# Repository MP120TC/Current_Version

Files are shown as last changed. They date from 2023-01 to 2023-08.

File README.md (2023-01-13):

# MP120TC (Version1, December 2022)
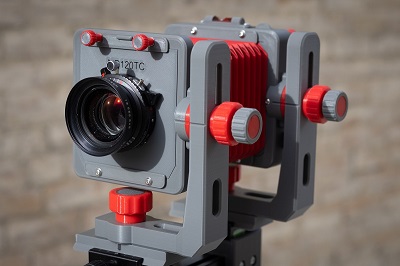
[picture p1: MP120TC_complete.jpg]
MP120TC complete camera


The MP120TC is a 120 film technical camera designed by Kent Williams in 2022.  It has full tilt/shift/swing/rise/fall movements on both the front and rear standards to enable full control of focus plane and geometry just like a large format view camera.  It uses Graflok 23 compatible roll film backs for convenience, and the parts that move most utilize off-the-shelf metal parts for durability, smoothness, and precision.  You can even build your own bellows for it if you're up to the task.  The camera will work with any large format lens in shutter as long as there's enough image circle and you have the proper rail/bellows length combination.  Most of the camera is 3D printed, so when parts wear out, you just print another!

## License
The MP120TC is provided to the community using a [Creative Commons Attribution-NonCommercial 4.0 license](https://creativecommons.org/licenses/by-nc/4.0/)
This means you can Share or Adapt/Remix it, as long as you provide attribution and don't sell the design. See [this page](https://creativecommons.org/licenses/by-nc-sa/4.0/legalcode) for more details.

 

# Website
The MP120TC also has its own website, which can be found here:  [MP120TC Website](https://williamskg6.wixsite.com/mp120tc)
## Why I Designed The MP120TC
In 2021 I got my first 3D printer.  I'd been designing things and having them printed at outlets like Shapeways and Xometry for several years. With this new 3D printer in my possession I decided to print and build an open source 120 film technical camera I had found online.  It looked nice in pictures and all the files were available, so I was pretty sure it'd work ... or so I thought.

Once I started printing parts, I had a realization that the camera had several pretty important faults.  The idea was cool, and it would look nice on the shelf, but it wouldn't really be usable. I first attempted to modify the existing design and immediately ran into more problems, since many design decisions were built into the models that conflicted with the idea of making a usable camera.  I came to the realization that it'd probably be better if I started from scratch and designed my own.

## How It Got Its Name
Early on in my designing process I had discovered a project called the MPCNC, which stands for "Mostly (3D) Printed CNC", which is a CNC router you can build using a combination of 3D printed parts and off-the-shelf hardware.  The idea is to construct the router using mostly 3D printed parts, and augment those parts with hardware that is better suited in only those places where the hardware is better for the task.  I think this is a pretty clever idea, and I adopted it for my 3D printed technical camera.  It is mostly 3D printed, augmented with parts where 3D printing would be less effective.  It's a 120 technical camera, so I named it the Mostly Printed 120 Technical Camera, or MP120TC for short.

## 120 Film Instead of 4x5
There are several reasons I chose 120 film, specifically 6x7cm, over 4x5 inch film:
- There are numerous 4x5 3D printable camera designs already available
- 4x5 inch film is considerably more expensive per shot
- 4x5 inch film is considerably less convenient and much more cumbersome to carry
- 4x5 inch film is much more expensive to develop if you send it to a lab
- 4x5 inch film is a lot more difficult to scan
- 6x7cm image quality is very high and can almost approach the quality of 4x5 inch film
- 120 film is much easier to get and is much less expensive
- If you want to use a lab to process your film, 120 film is much less expensive
- Scanning 120 film is a lot easier and less expensive
- 120 film backs are readily available, made by Mamiya, Graflex, or Horseman

## 6x7 By Default, 6x9 Optional
By default, the MP120TC is a 6x7cm camera that employs the Graflok 23 roll film mount (sometimes called Graflok Mini).  Because Graflok 23 was built to handle it, the MP120TC can also support 6x9 if desired.  I've been asked why I chose 6x7 as the default when I could have gone with 6x9 instead.  Here are the reasons I've chosen 6x7cm by default. 

6x7 film backs are much more plentiful.  The most common 6x9 film backs are from Graflex and Horseman, while with 6x7 you can use Mamiya RB-67 backs, Graflex, and Horseman.  While the Horseman backs are really nice, they're not very easy to get.  Graflex backs are pretty common, but are not as well made as Mamiya and Horseman, nor do they hold film as flat as Mamiya and Horseman backs.

For the 6x7 size, there are more options available for the ground glass, especially from Rick Oleson Bright Screens.  In 6x7 size, you can get screens with many different focusing aids (splits, microprisms, etc.) and lines for other formats.  With 6x9 you can only get plain focusing screens, cut down from 4x5 inch screens.

As you can see, there aren't many reasons, but the film back availability is a pretty important one.  Having said that, those who wish to go for 6x9 can totally do so - the files are included.

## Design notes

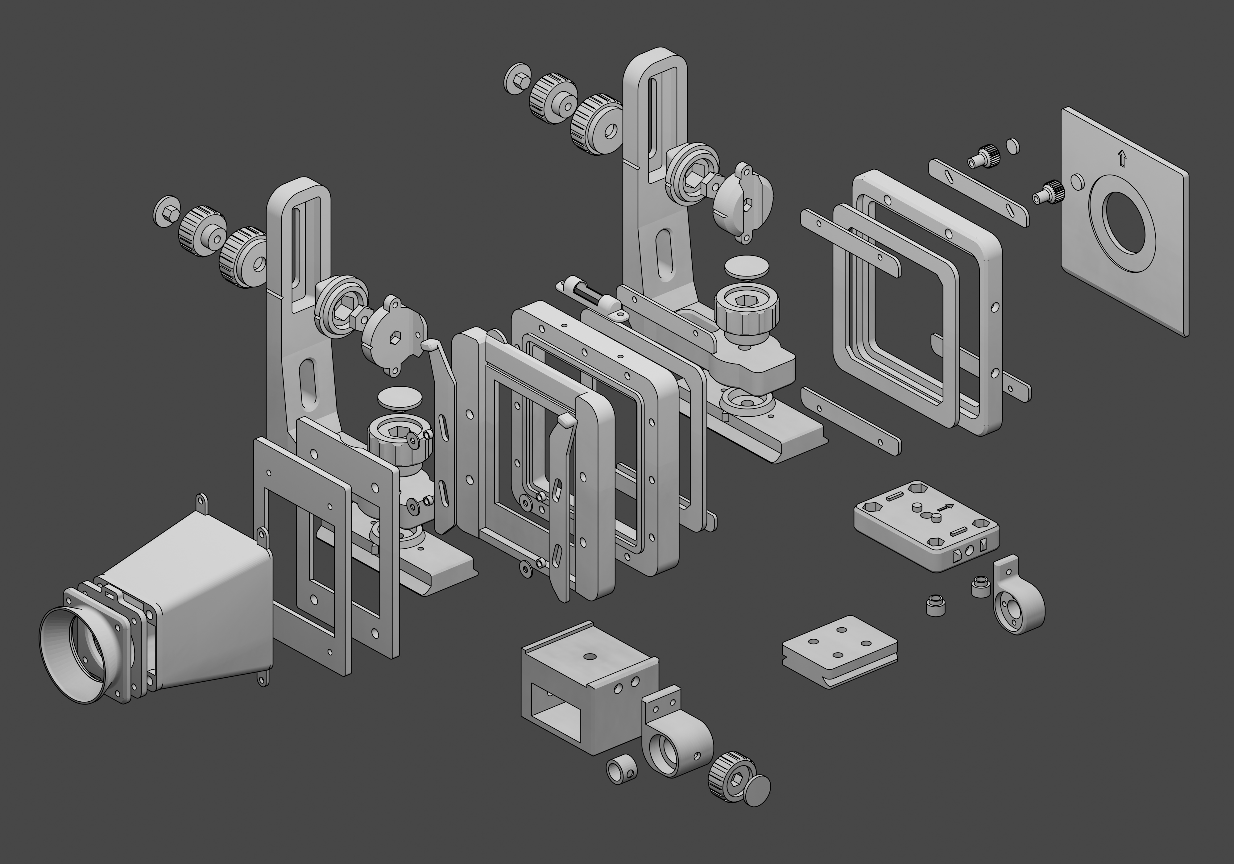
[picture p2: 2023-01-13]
Full_Camera_Exploded_View.jpg

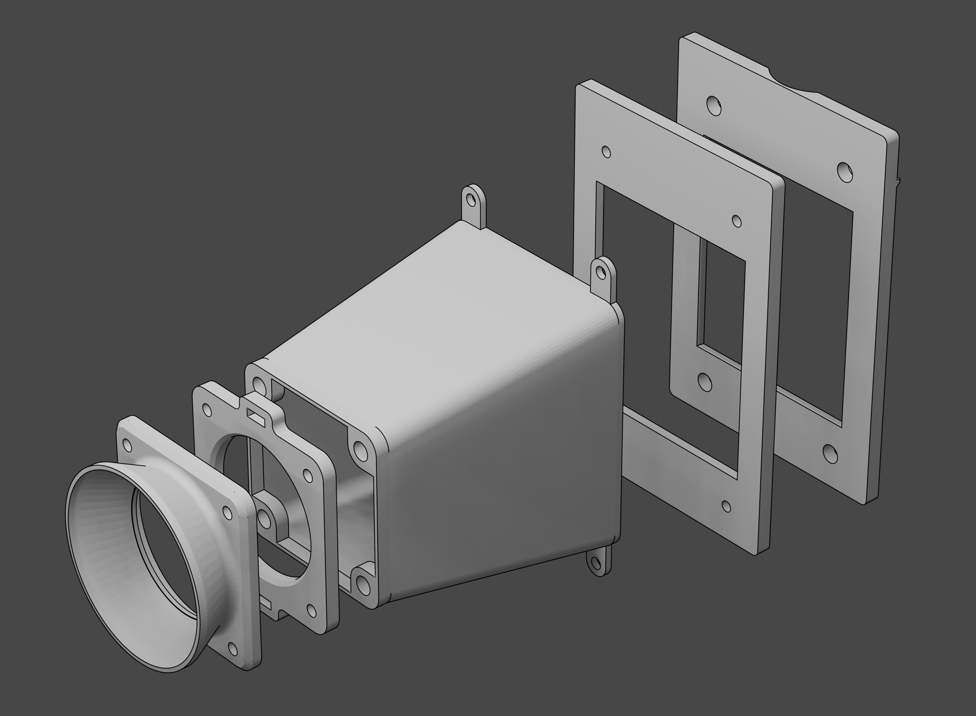
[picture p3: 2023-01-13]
Ground_Glass_Holder_Focusing_Hood.jpg

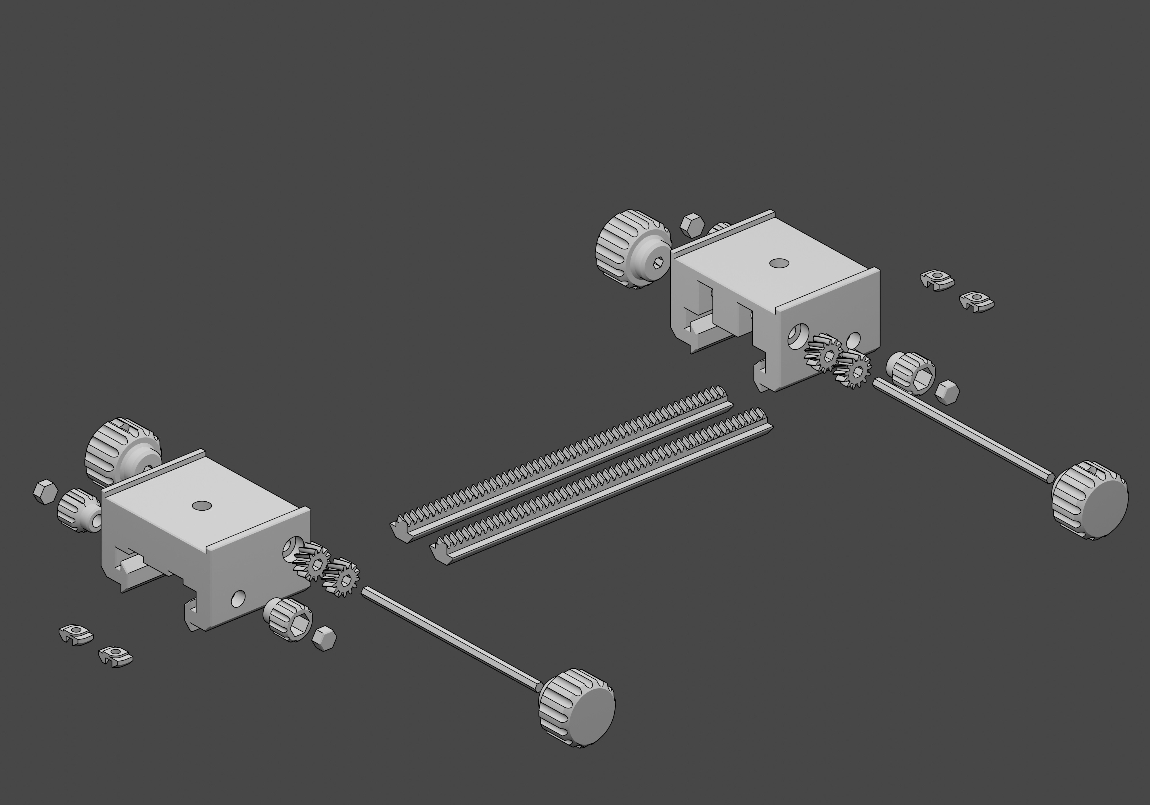
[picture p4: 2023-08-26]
Focusing_Mechanism.jpg

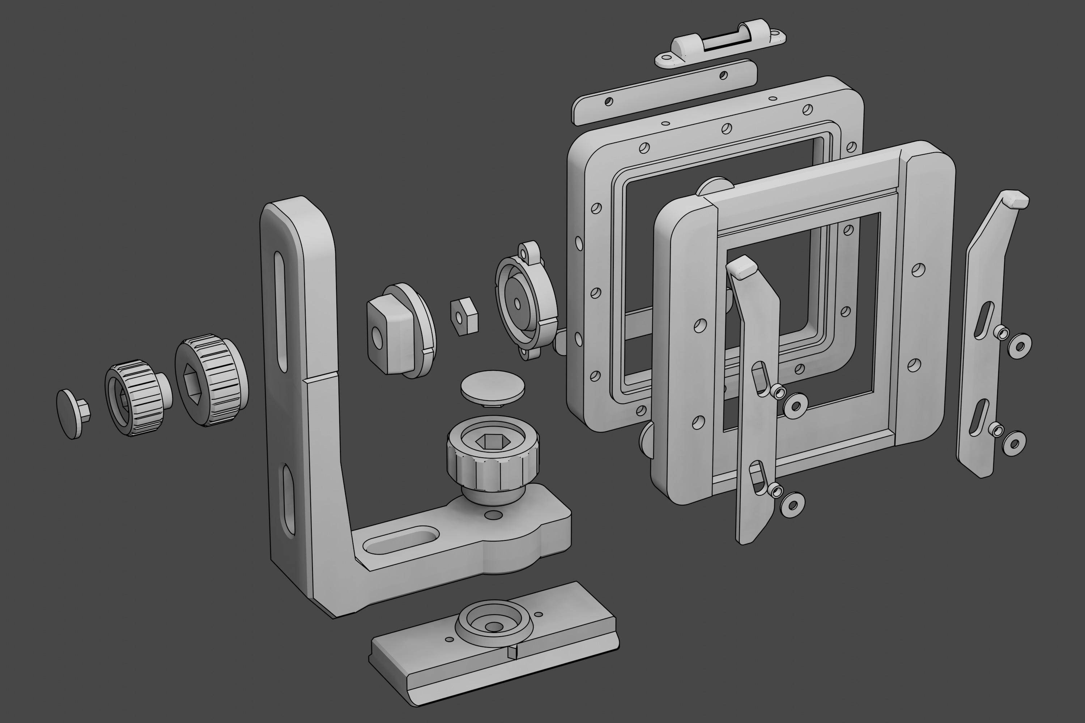
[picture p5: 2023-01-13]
Back_LFrame_and_Graflok_Back.jpg

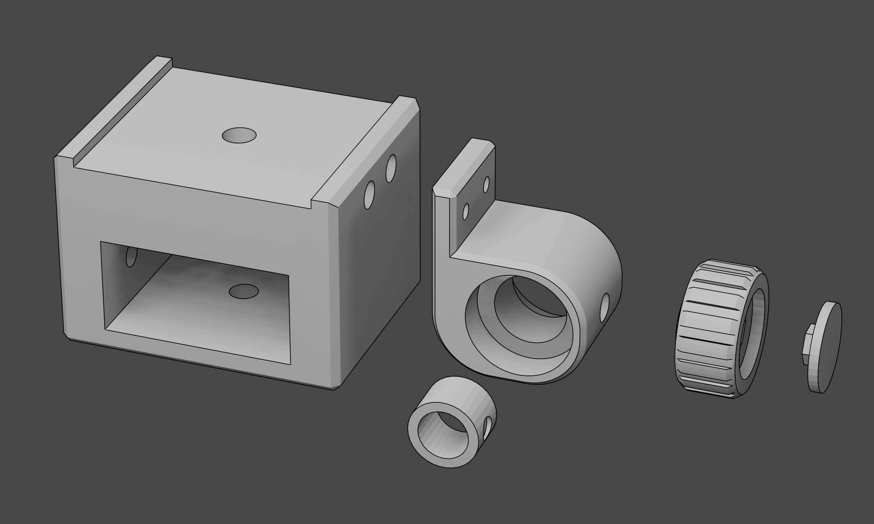
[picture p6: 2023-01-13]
Rear_Rail_Mount.jpg

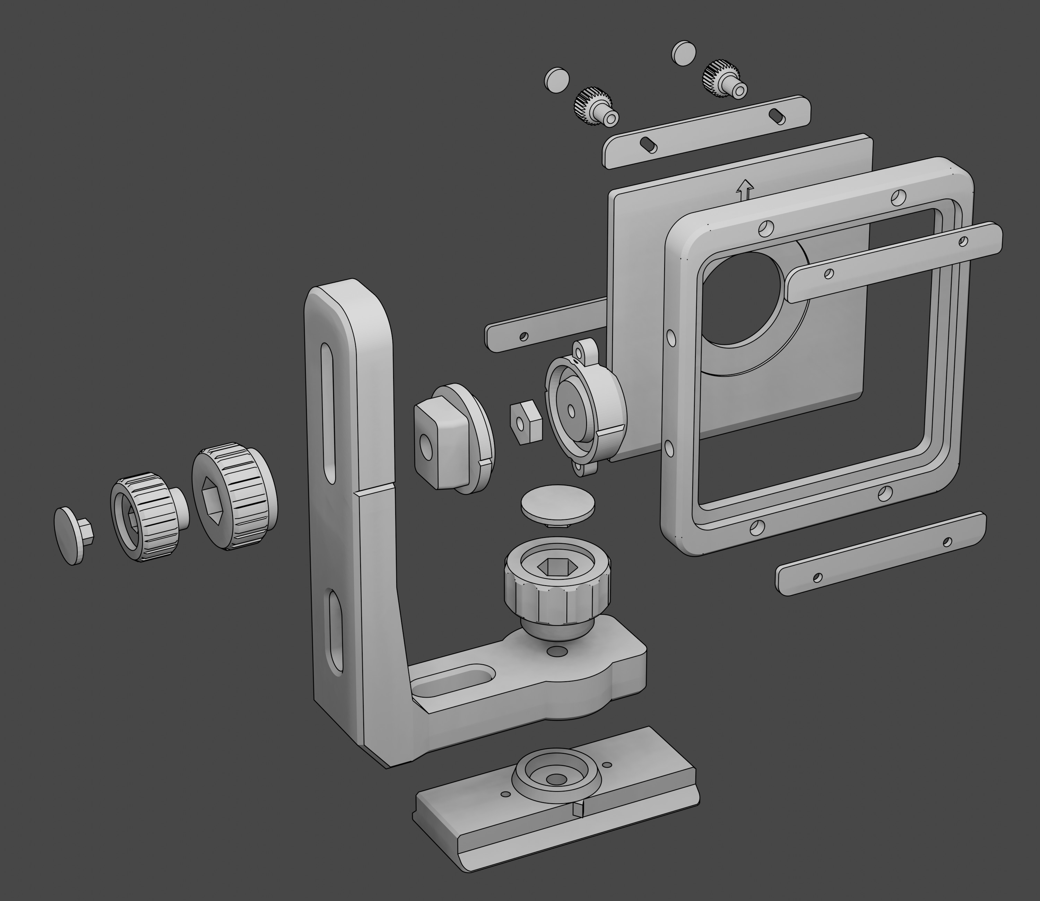
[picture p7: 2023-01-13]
Front_LFrame_and_Lens_Frame.jpg

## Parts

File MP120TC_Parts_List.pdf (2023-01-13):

Part | Quant. Needed | Time Each (Hours) | Filament Usage Each (grams) | Filament Usage (grams) | Settings
Rise/Fall Block | 2 | 0.983 | 8 | 16 | 0.2 layer height, 3 walls, 50% infill, adaptive layers, tree support with lines interface, flip part so trapezoid mating surface is facing upward
Rise/Fall Knob | 2 | 0.933 | 9 | 18 | 0.2 layer height, 3 walls, 50% infill, supports, adaptive layer height
Tilt Block (front) | 1 | 1.283 | 10 | 10 | 0.2 layer height, 3 walls, 60% infill, adaptive layers, flipped so frame interface slot is down, use normal supports, random z seam
Tilt Block (rear) | 1 | 1.200 | 8 | 8 | 0.2 layer height, 3 walls, 60% infill, flipped so swing mating surface is down, use normal supports, random z seam
M8 plug for Rise/Fall block | 2 | 0.083 | 1 | 2 | 0.2 layer height, 3 walls, 60% infill, adaptive layers
Tilt Knob | 2 | 1.033 | 7 | 14 | 0.16 layer height, 3 walls, 60% infill, adaptive layers, supports, random z seam
Tilt Knob Cap | 2 | 0.117 | 1 | 2 | 0.2 layer height, 3 walls, 20% infill, adaptive layers, random z seam
Front L Arm | 1 | 9.950 | 84 | 84 | 0.2 Layer height, 3 walls, alternate extra wall, 40% infill, supports, suport blockers on zero grooves & detents
Rear L Arm | 1 | 10.083 | 87 | 87 | 0.2 Layer height, 3 walls, alternate extra wall, 40% infill, supports, suport blockers on zero grooves & detents
Repositionable Back | 1 | 6.000 | 52 | 52 | 0.2 layer height, 3 walls, 30% infill, supports, support blockers on all magnet holes.
Repositionable Back Frame | 1 | 7.117 | 66 | 66 | 0.2 layer height, 3 walls, alternate extra wall, 30% infill, supports, support blockers on all M3 holes.
Swing Knob | 2 | 1.500 | 14 | 28 | 0.2 layer height, 3 walls, 50% infill, supports, adaptive layer height
Swing Knob cap | 2 | 0.183 | 1 | 2 | 0.2 layer height, 3 walls, 50% infill
Frame QR Slider | 2 | 2.950 | 28 | 56 | 0.2 layer height, 3 walls, 50% infill, supports
Bellows locking plates | 5 | 0.250 | 2 | 10 | 0.2 layer height, 3 walls, 50% infill
Front Frame | 1 | 5.800 | 47 | 47 | 0.2 layer height, 3 walls, 50% infill, supports
Bellows Frame | 2 | 1.367 | 11 | 22 | 0.2 layer height, 3 walls, 50% infill
Lens Board | 1 | 3.500 | 31 | 31 | 0.2 layer height, 3 walls, alternate extra wall, 50% infill, adaptive layers
Lens Board Sliding Plate | 1 | 0.283 | 2 | 2 | 0.2 layer height, 3 walls, 50% infill
M3 Thumbscrew | 2 | 0.317 | 1 | 2 | 0.2 layer height, 3 walls, 50% infill, supports
M3 Thumbscrew Cap | 2 | 0.033 | 0.1 | 0 | 0.2 layer height, 3 walls, 50% infill
Ground Glass Holder (front) | 1 | 2.500 | 21 | 21 | 0.2 layer height, 3 walls, 50% infill
Ground Glass Holder (rear) | 1 | 2.217 | 17 | 17 | 0.2 layer height, 3 walls, 50% infill
Graflok slider | 2 | 0.617 | 4 | 8 | 0.2 layer height, 3 walls, 50% infill
Graflok slider spacer | 4 | 0.017 | 0.1 | 0 | 0.2 layer height, 3 walls, 50% infill
Graflok slider washer | 4 | 0.017 | 0.1 | 0 | 0.2 layer height, 3 walls, 50% infill
Rear Focusing Mount | 1 | 1.850 | 14 | 14 | 0.2 layer height, 3 walls, 50% infill, supports, flip part so bore is vertical
Front Carriage Focusing Mount | 1 | 0.917 | 7 | 7 | 0.2 layer height, 3 walls, 50% infill, flip part so lead screw nut mount is facing upwards
Lead Screw Sleeve | 1 | 0.150 | 1 | 1 | 0.2 layer height, 4 walls
Magnifying Hood Eye Cup | 1 | 1.250 | 8 | 8 | 0.2 layer height, 3 walls, 50% infill, supports
Magnifying Hood Tunnel | 1 | 5.283 | 37 | 37 | 0.2 layer height, 3 walls, tree supports
Magnifying Hood Lower Lens Holder | 1 | 0.850 | 6 | 6 | 0.2 layer height, 3 walls, supports, 50% infill
Front Carriage | 1 | 3.233 | 30 | 30 | 0.2 layer height, 3 walls, supports, 50% infill
Focus lock knob | 1 | 0.683 | 5 | 5 | 0.2 layer height, 3 walls, supports, 50% infill
Focus lock knob cap | 1 | 0.117 | 1 | 1 | 0.2 layer height, 3 walls, 50% infill
Rail tripod mount | 1 | 2.050 | 17 | 17 | 0.2 layer height, 3 walls, 50% infill, supports, flip so top surface of part faces downward
Front Carriage wheel spacers | 2 | 0.117 | 0.1 | 0 | 0.2 layer height, 3 walls, 50% infill
Bubble Level Holder | 1 | 0.283 | 1 | 1 | 0.16 layer height, 3 walls, 50% infill
Recessed Lens Board | Optional

Item | Description | Quantity | Example Source URL
Arca quick release plate | Arca compatible quick release plate for horizontal slide and quick disassembly | 2 | https://www.ebay.com/itm/264632467937?hash=item3d9d5301e1:g:9f4AAOSwfTpfdLnu
M3 button head screws | M3 screws to be used throughout | 1 | https://www.amazon.com/HELIFOUNER-Pieces-Button-Washers-Stainless/dp/B09WJ1C8JP
M4 x 45mm hex head screws | For tilt knobs, preferably stainless steel | 2 | https://www.boltdepot.com//Product-Details.aspx?product=23434
1/4-20 x 1.5" Hex head bolts and nuts | For swing knobs, preferably stainless steel | 2 | Just about any hardware store
M3 heat set threaded inserts | | pack of 50 | https://www.amazon.com/initeq-M3-0-5-Threaded-Inserts-Printing/dp/B077CL322T
M4 heat set threaded inserts | | pack of 20 | https://www.amazon.com/initeq-M4-0-7-Threaded-Inserts-Printing/dp/B07457F9ST
20x40 Aluminum extrusion | Length depends upon focal length of lens you want to use | 1 | https://openbuildspartstore.com/v-slot-20x40-linear-rail/
8mm Lead Screw | Length should be similar to extrusion | 1 | https://openbuildspartstore.com/8mm-metric-acme-lead-screw/
Jog Knob | | 1 | https://openbuildspartstore.com/jog-knob/
Lock collar | | 1 | https://openbuildspartstore.com/lock-collar/
Round lead screw brass nut | | 1 | https://www.amazon.com/ReliaBot-Thread-Starts-Diameter-Printer/dp/B079HQ386R
Delrin mini v wheels | | 4 | https://openbuildspartstore.com/delrin-mini-v-wheel-kit/
M5 lock nuts | | 1 pack | https://openbuildspartstore.com/nylon-insert-hex-locknut-m5-10-pack/
Double Tee nut | | 3 | https://openbuildspartstore.com/double-tee-nut/
M5x30mm low profile screws | | 1 pack | https://openbuildspartstore.com/low-profile-screws-m5-10-pack/
M5x10mm screws | | 2 | Most hardware stores
6mm Eccentric spacer | | 2 | https://openbuildspartstore.com/eccentric-spacer/
M8x20mm Hex head hollow bolts (M4 hole) | Center hole should be 4.2mm to allow M4 bolt, must have hex head | 2 | https://www.amazon.com/dp/B09VL3D34G
M8 nuts | | 2 | Most hardware stores. If you order the above bolts from Amazon, the nuts come with them
Standard 22mm OD skateboard bearings | 608 style, with 8mm inner diameter. No need for expensive bearings! | 2 | Many, many brands and sources - Amazon or a local skate shop
Ground Glass, 68x78x1.5mm | Plain ground glass is fine and less expensive, but strongly consider bright screen | 1 | https://rickoleson-brightscreen.com/
Bellows | 100x100mm outer dimensions on front & back, 80x80mm inner dimensions on front and back. Length will be determined by focal length of your lens | | http://www.custombellows.co.uk/
9mm OD 0.4mm wall thickness steel tubing | Optional - for more durable focusing lock - cut a 10mm section | 1 | https://www.amazon.com/uxcell-Stainless-Thickness-Seamless-Straight/dp/B081J38P11

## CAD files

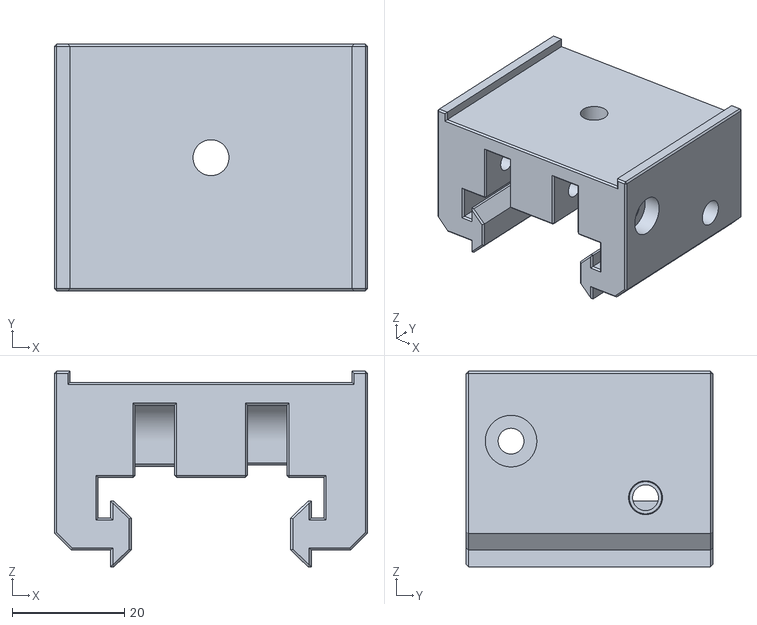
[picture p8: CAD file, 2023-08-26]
Focusing_Carriage.stl
55.8 x 44.0 x 35.0

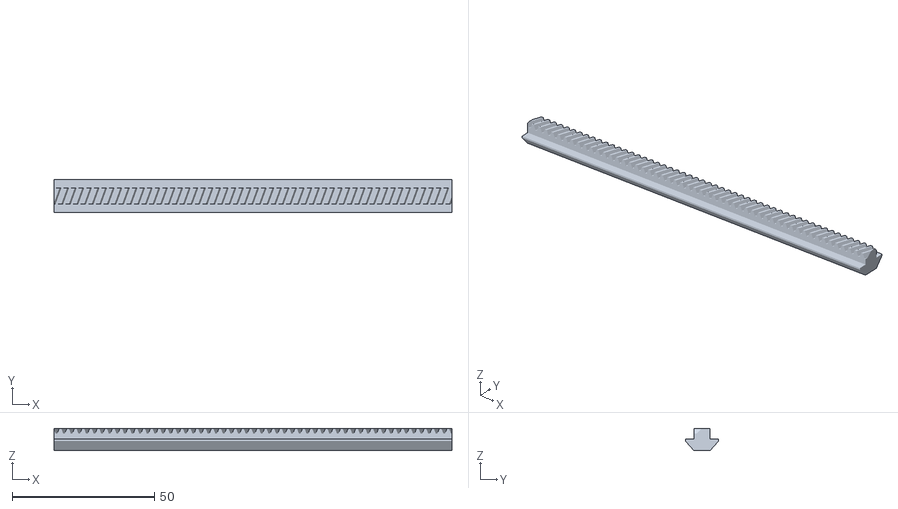
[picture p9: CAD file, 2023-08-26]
Focusing_Rack_140mm.stl
140.0 x 11.8 x 7.80

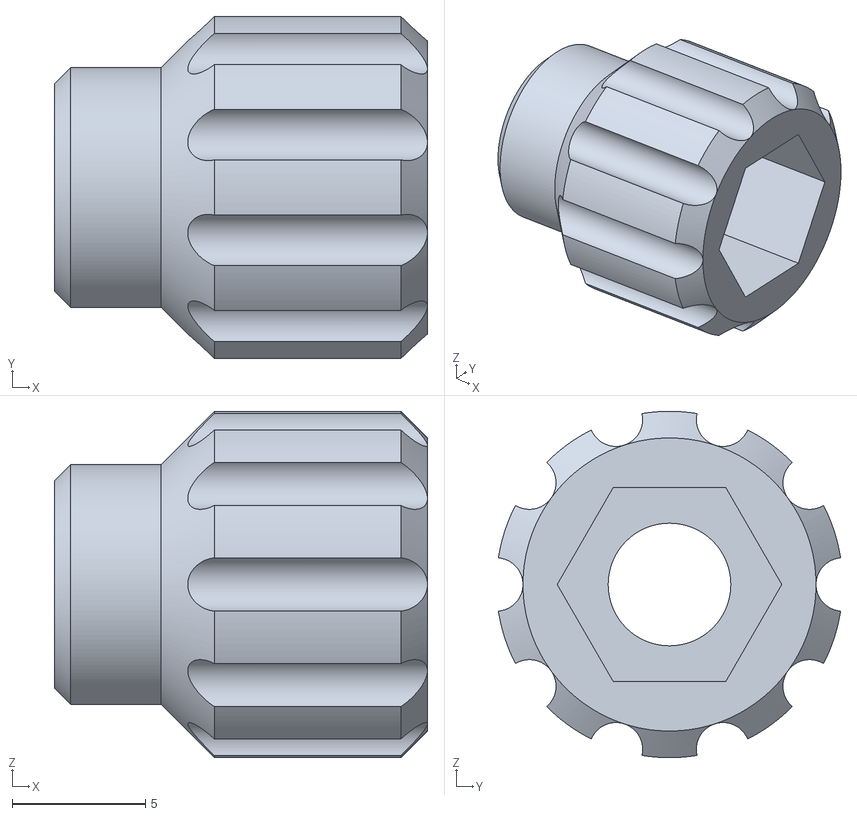
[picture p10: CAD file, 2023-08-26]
Focus_Locking_Knob.stl
14.0 x 12.8 x 13.0

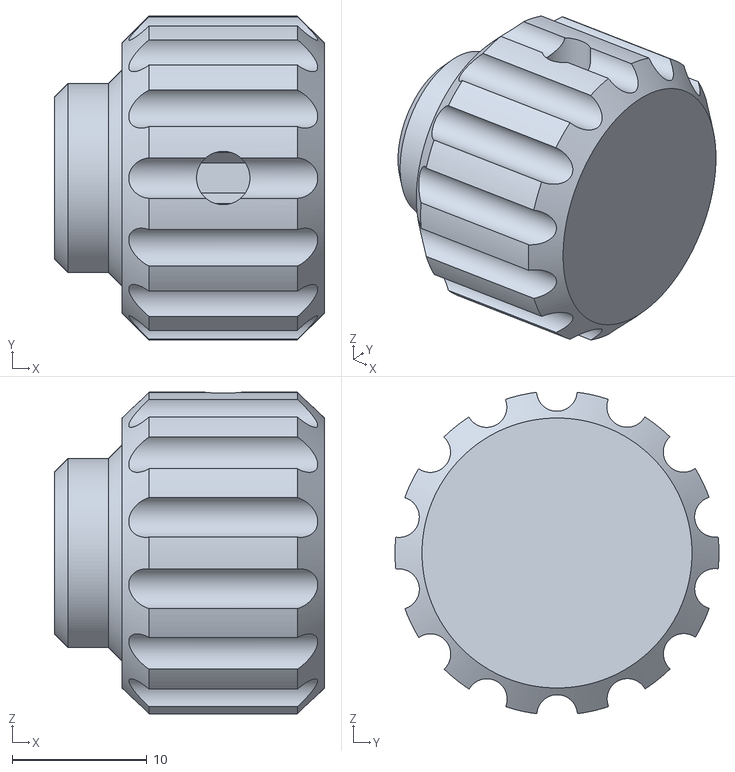
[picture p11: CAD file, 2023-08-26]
Focusing_Knob.stl
20.0 x 24.0 x 23.8

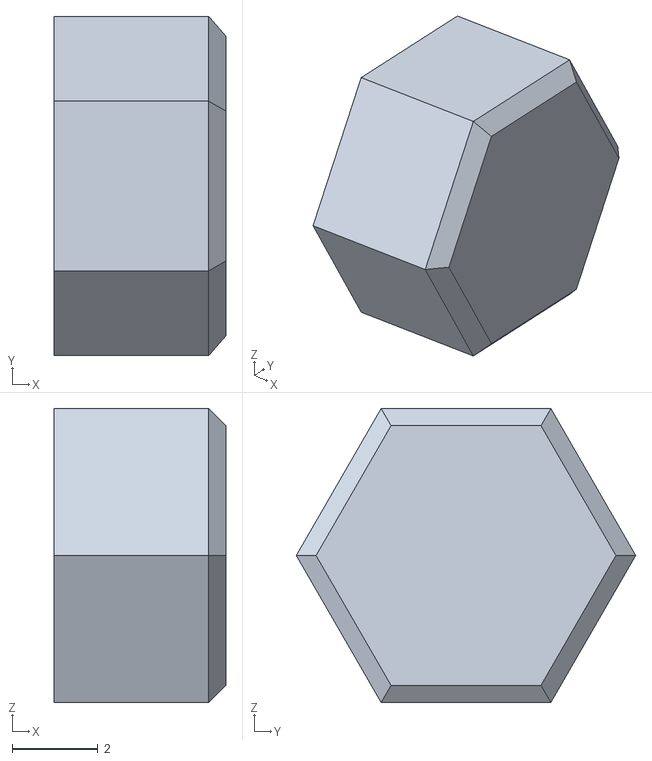
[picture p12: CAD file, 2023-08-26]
Focus_Locking_Knob_Cap.stl
4.00 x 7.91 x 6.85

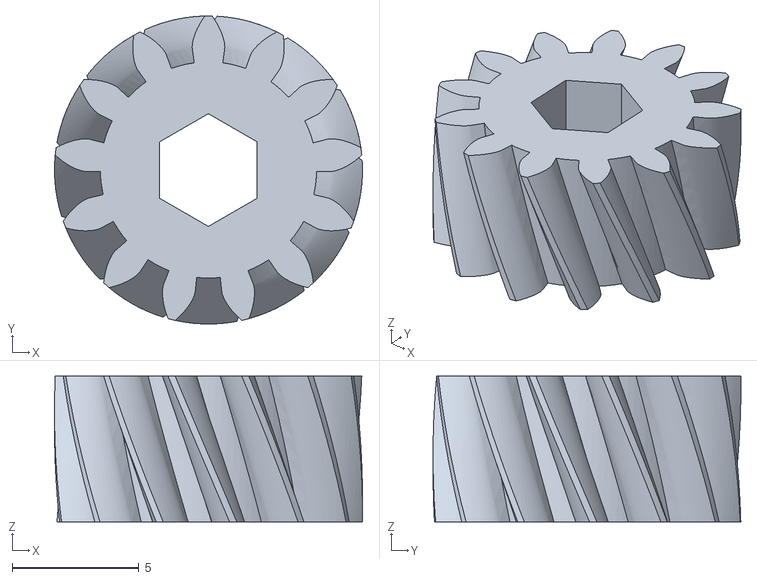
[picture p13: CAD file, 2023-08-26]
Focusing_Pinion.stl
12.2 x 12.2 x 5.75

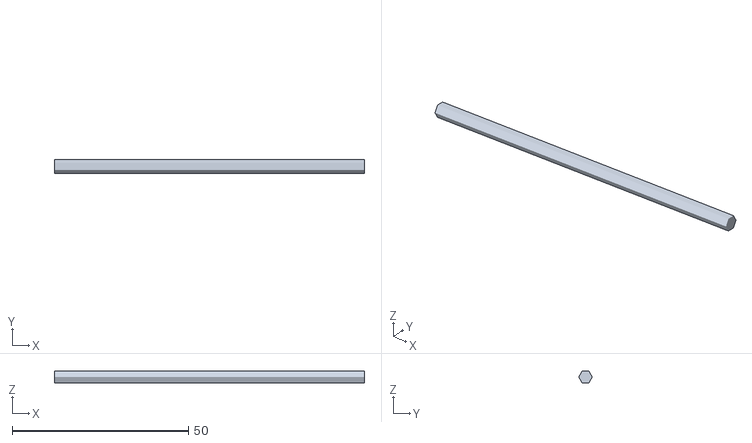
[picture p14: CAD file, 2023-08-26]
Focusing_Hex_Axle.stl
88.0 x 3.87 x 3.35

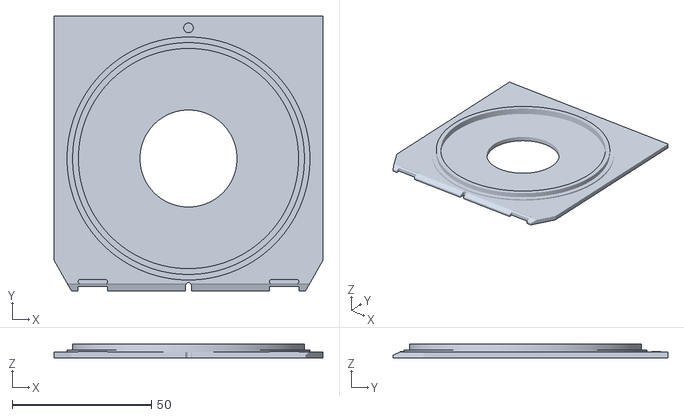
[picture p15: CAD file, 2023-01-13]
linhof_board_copal_0.stl
96.5 x 98.7 x 5.00

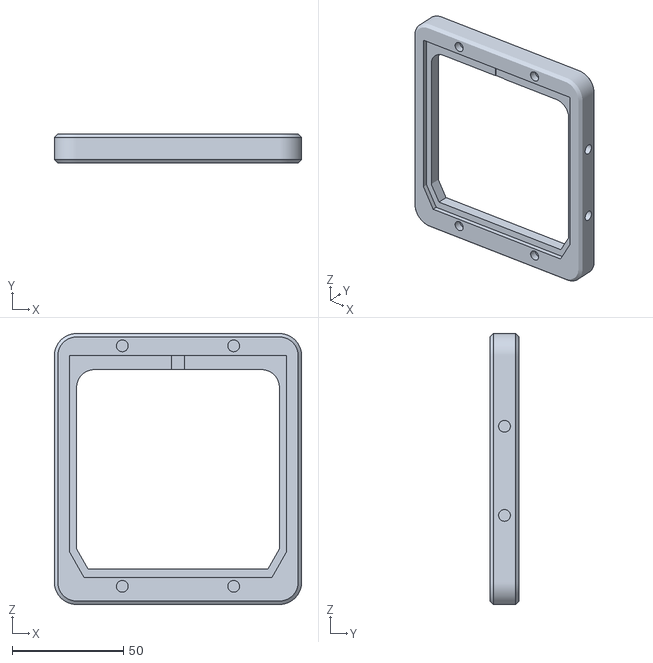
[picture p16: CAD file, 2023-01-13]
Front_Lens_Frame_Linhof.stl
111.0 x 13.0 x 121.7

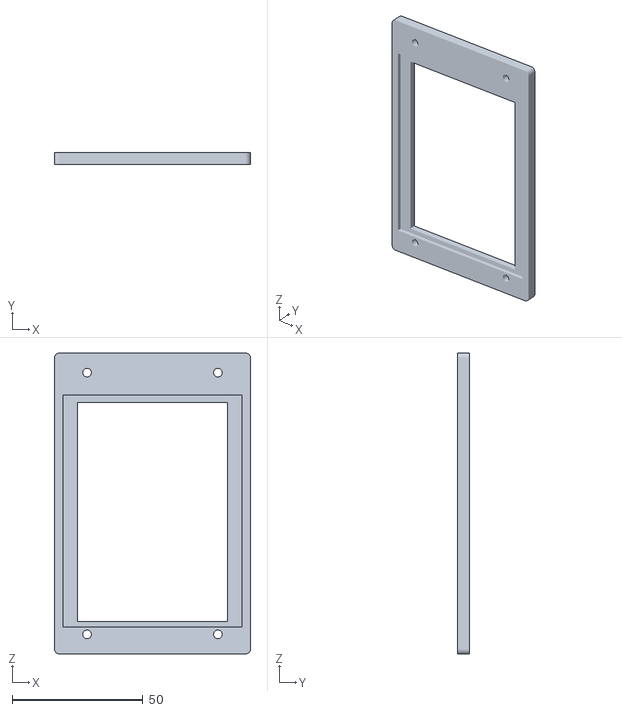
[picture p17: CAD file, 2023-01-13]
GroundGlassFrame_rear_6x9.stl
75.0 x 4.50 x 115.0

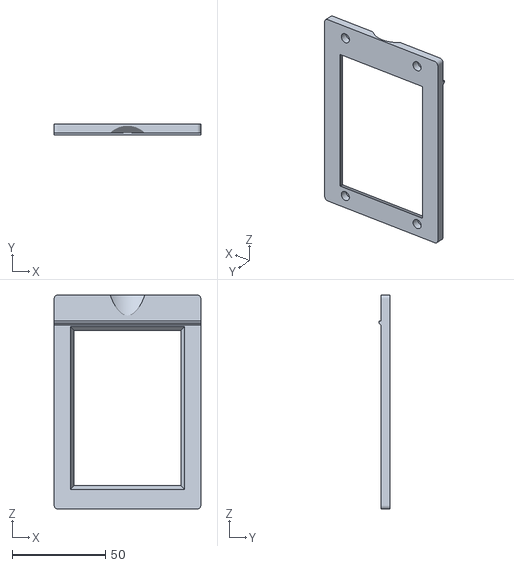
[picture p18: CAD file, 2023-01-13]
GroundGlassFrame_front_6x9.stl
78.8 x 5.83 x 115.0

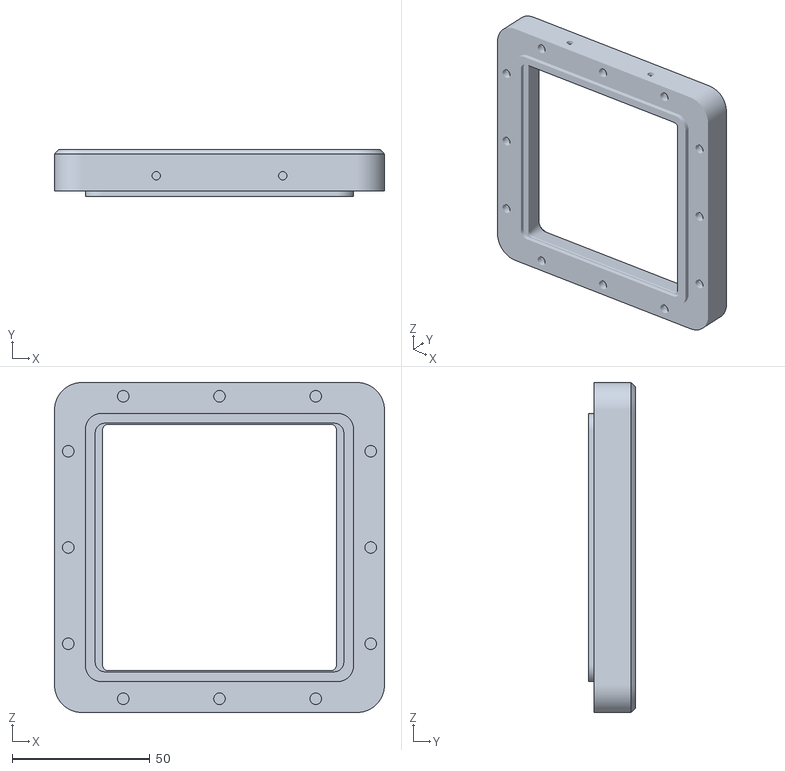
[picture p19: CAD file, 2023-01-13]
Rear_Frame_6x9.stl
120.0 x 17.0 x 120.0

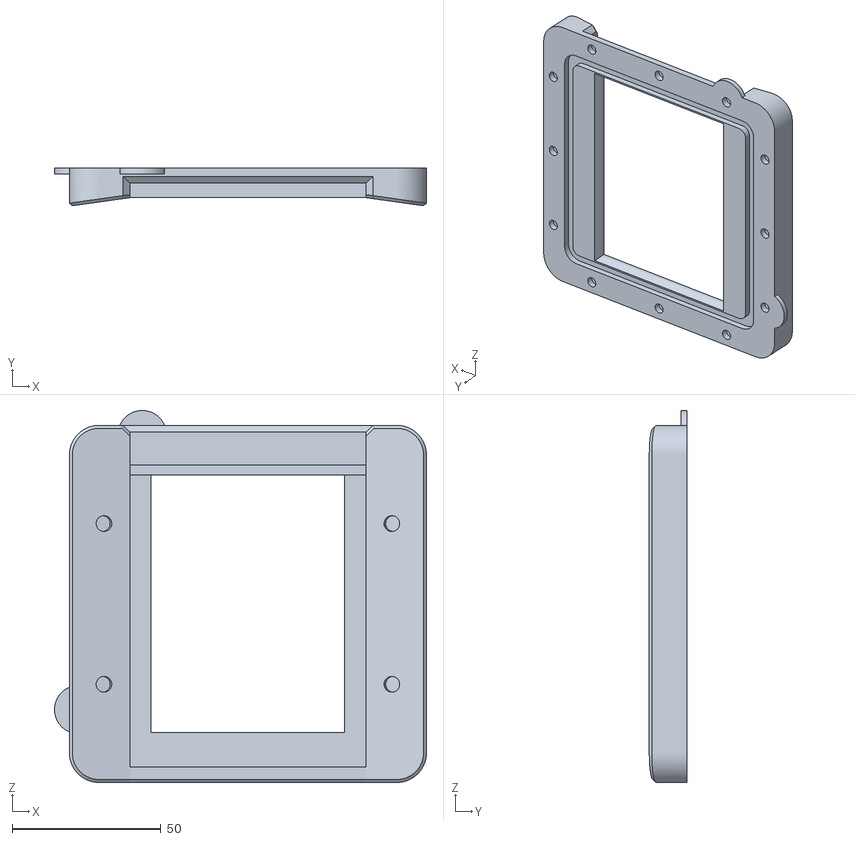
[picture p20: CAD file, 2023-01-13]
Repositionable_Back_6x9.stl
125.0 x 12.6 x 125.0

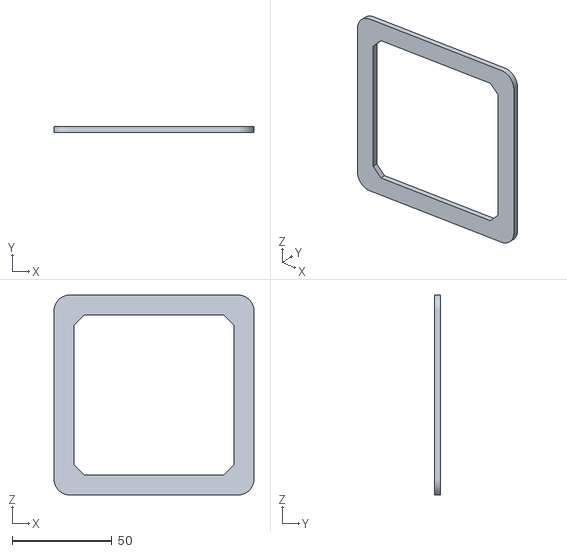
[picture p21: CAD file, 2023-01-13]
Bellows_Frame.stl
100.0 x 3.00 x 100.0

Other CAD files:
Copal_0_lens_board.stl
Tilt_knob_cap.stl
Graflok_Sliding_Plate.stl
Graflok_Slider-Spacer.stl
Bellows_Locking_Plate.stl
Bubble_Level_Holder.stl
Frame_QR_Slider.stl
Front_L_Arm.stl
Front_Lens_Frame.stl
Front_Tilt_Block.stl
Graflok_Slider-Washer.stl
GroundGlassFrame_front.stl
GroundGlassFrame_rear.stl
Lens_Board_Sliding_Plate.stl
M3_Thumbscrew.stl
M3_Thumbscrew_Cap.stl
M8_Plug.stl
Magnifying_Hood_EyeCup.stl
Magnifying_Hood_Lower_Lens_Holder.stl
Magnifying_Hood_Tunnel.stl
Rail_Tripod_Mount.stl
Rear_Frame.stl
Rear_L_Arm.stl
Rear_Rail_Mount.stl
Rear_Tilt_Block.stl
Repositionable_Back.stl
Rise_Fall_Block.stl
Rise_Fall_knob.stl
Swing_Knob.stl
Swing_Knob_cap.stl
Tilt_knob.stl

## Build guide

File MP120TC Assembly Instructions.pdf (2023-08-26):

# MP120TC Assembly Instructions

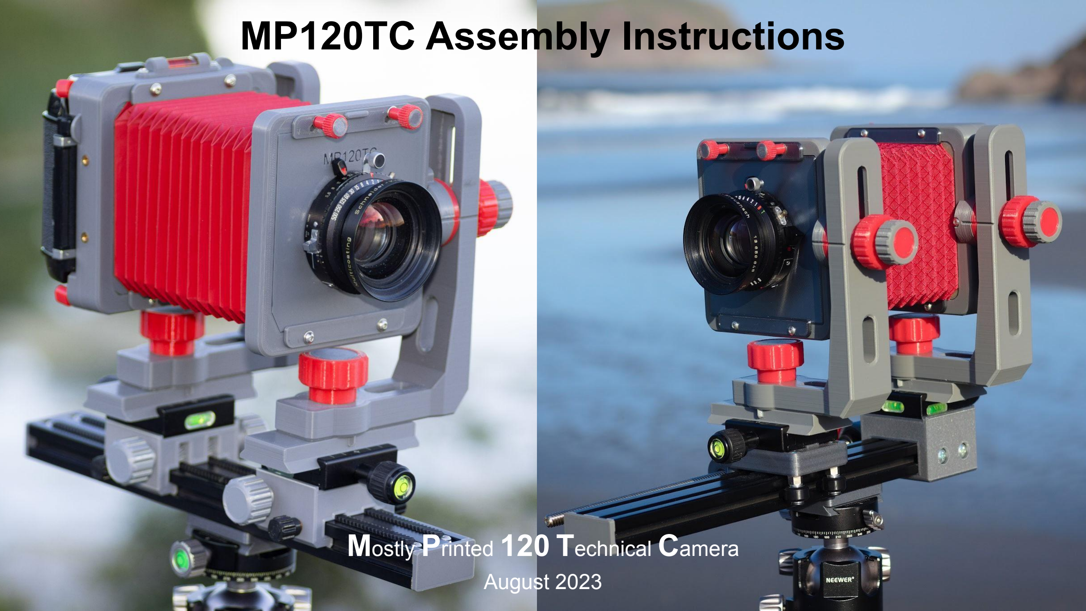
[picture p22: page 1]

Mostly Printed 120 Technical Camera

August 2023

# Introduction

In Summer 2021 I decided to build a Goodman Axis technical camera, having found it online. I began printing the files provided and quickly noticed that the camera’s design had flaws, some of which would completely prevent the camera from being usable. Due to these issues, I determined that the amount of time involved in modifying the design was not worth the effort and that I would start my own design from scratch.

I was inspired by the Mostly Printed CNC (MPCNC), where as many parts as possible are 3D printed, augmented by off-the-shelf hardware and parts where needed. I decided that I would follow this design philosophy and make a Mostly Printed 120 Technical Camera (MP120TC).

After about a year of work and refinements, the MP120TC was working and ready for the world. In this document you will find instructions on how to assemble one for yourself.

# Format

The default format, which is also the recommended format, is 6x7cm on 120 film (6x9 is possible*). This was selected over 4x5 inches for several reasons.

- 120 film is much more convenient to work with.
- 120 film is also considerably less expensive to purchase and easier to find labs to process.
- If you process the film yourself, 120 film is considerably easier to work with.
- Once developed, 120 film is also easier to get scans from when working in an analog/digital hybrid workflow.
- The cost overall is at least ¼ that of 4x5 film and image quality is comparable at most common print sizes.

*Files for 6x9-capable film backs are included if you want to use them, but 6x7 is recommended.

# Film Backs

This camera is compatible with Graflok 23 style film backs, primarily Graflex RH10 and Mamiya RB-67 backs. The sliders that secure the backs will catch the darkslide release on Mamiya Pro-S and Pro-SD backs, so any RB 6x7 film back should work. 6x9 backs can be used provided you use the rear frame, repositionable plate, and ground glass holder parts designed for 6x9. Other Graflok 23 backs such as Horseman and Linhof should work, but they have not been tested. Additionally, you may use Graflok 23 compatible cut film holders, should you happen to have them and don’t mind the inconvenience!

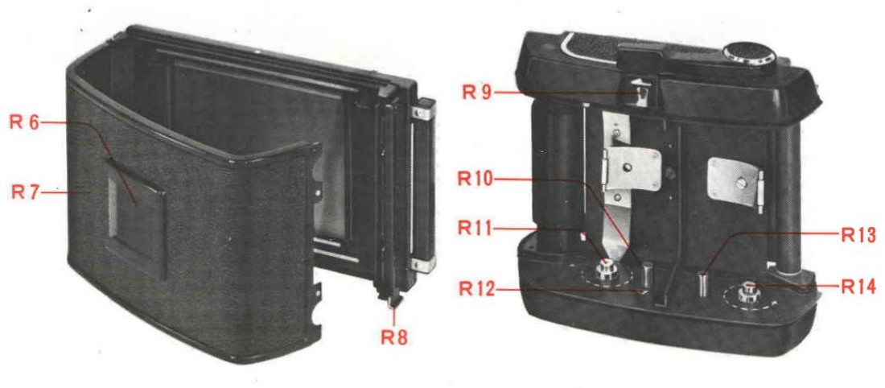
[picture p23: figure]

# Lenses

Any lens over 75mm in focal length in a #00, #0, or #1 shutter that covers 6x7cm can be used. The most common lenses are those designed for 4x5 inch large format cameras in a #0 shutter. The lens you choose will dictate how long of a rail, how long the gear rack will need to be, and how long of a bellows you need.

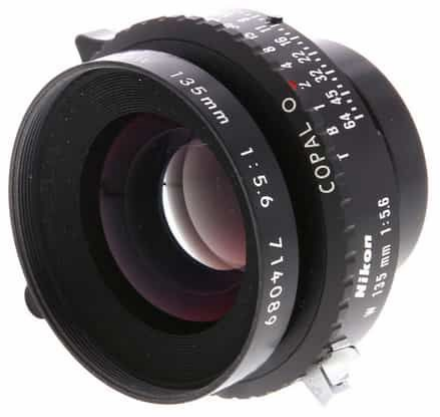
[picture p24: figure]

# Before You Start Printing Parts

## Order the 2X M8 x 20mm hollow hex-head bolts

This camera uses M8 x 20mm hollow hex-head bolts for the concentric tilt/rise/fall on both the front and rear standards, with a hole through the center sufficient to clear a M4 screw. These parts can be difficult to find, and you may end up buying them from China. If you have a buddy with machine tools, you could have some common M8 x 20mm screws bored out for a M4 screw instead.

## Order the Bellows

While you could try to build one yourself, chances are you’ll spend a ton of time and more money than buying a professionally made one. You could order one from China, but shipping is occasionally totally unreliable, so it is recommended that you buy your bellows from Custom Bellows UK (http://www.custombellows.co.uk/). Their prices are good and the quality is high. Additionally, they will get the bellows to you in a reasonable amount of time.

Outer dimensions: 100x100mm Front, 100x100mm rear
Inner dimensions: 80x80mm Front, 80x80mm rear
Length/# of pleats: this is determined by the lens you choose. For a 150mm lens a bellows with 14 pleats seems to work well and allows for good close-focusing extension.

# Before You Start Printing Parts (continued)

This camera can accept plain ground glass or a bright screen. Plain ground glass will work OK, but it will be a little dim and gritty. In addition, plain ground glass will suffer from light falloff away from the center of the glass. If you really want to make your own, there are videos on YouTube that describe how to make a ground glass.

A bright screen will be more pleasant to use if you have the budget to buy one. For bright screens I recommend the Rick Oleson bright screens (https://rickoleson-brightscreen.com/). Other screens are available from many sources, but Rick Oleson’s are the best balance of price and quality.

Format | Ground Glass Size
6x7 (default, recommended format) | 68 x 78mm x 1.5mm
6x9 | 68 x 88mm x 1.5mm

# Exploded View

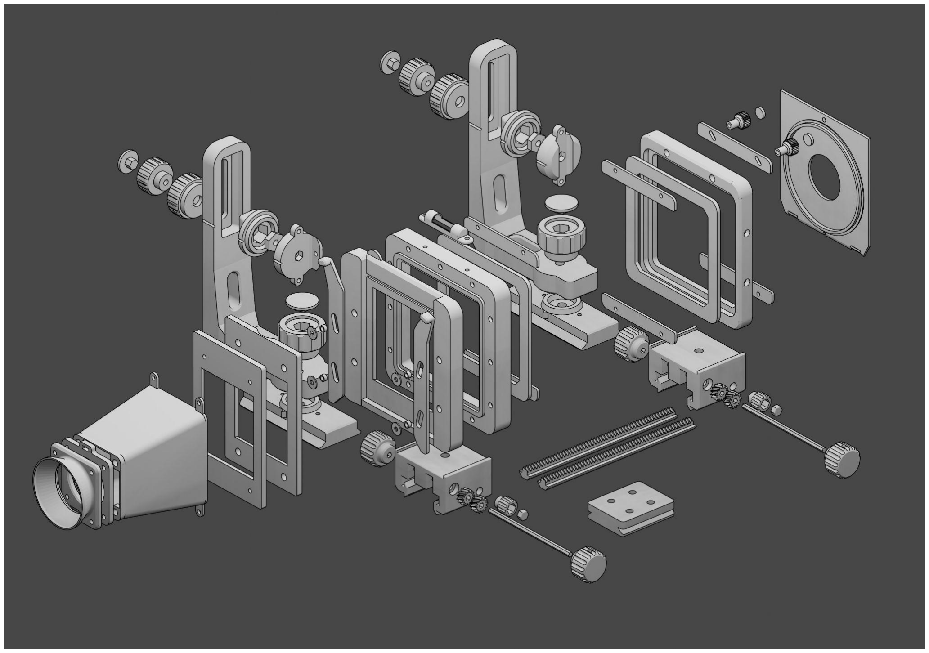
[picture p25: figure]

These are all of the 3D printed parts that comprise the MP120TC. Effort was made to minimize use of supports, and heat-set threaded inserts are used on most threaded screws for durability and strength. A standard FDM type 3D printer can be used to print all of these parts. PLA+ material is sufficient, but if you have the ability to print in stronger materials, it is recommended. With PLA you may occasionally need to replace parts as they wear.

There is no specific order of assembly. Individual 3D printed parts are assembled into larger part assemblies that you can build in the order of your choosing.

# Front L-Frame and Lens Frame

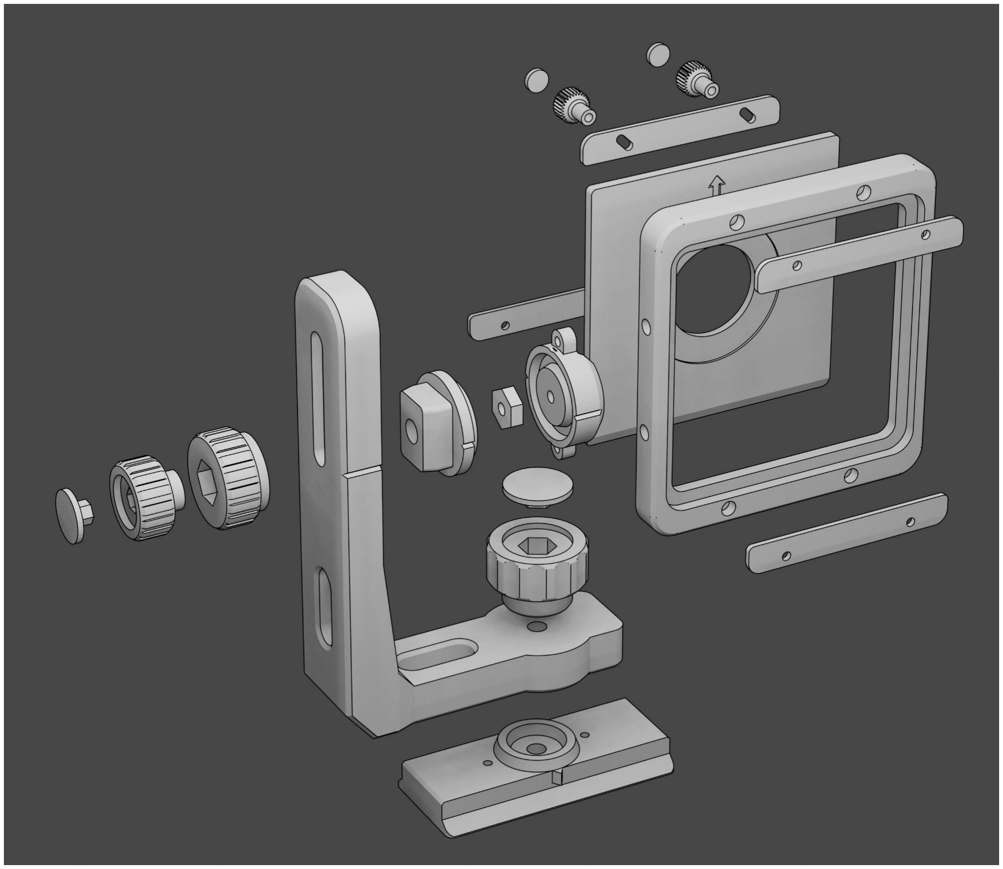
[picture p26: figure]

3D printed parts:
- 1X Frame QR Slider
- 1X Front L arm
- 1X Front lens frame*
- 1X Lens board*
- 1X Lens board sliding plate
- 3X Bellows locking plates
- 2X M3 thumbscrews
- 2X M3 thumbscrew caps
- 1X Front tilt block
- 1X Rise/Fall block
- 1X Rise/Fall knob
- 1X Tilt knob
- 1X Tilt knob cap
- 1X M8 plug
- 1X Swing knob
- 1X Swing knob cap

* Note: Several users requested that the front be modified to allow use of a Linhof Technika IV/V lens board. STL Files have been included for a Linhof lens board and an alternate Front lens frame that can accept the Linhof boards. You can decide which you wish to print.

Hardware:
- 1X M8 x 20mm hollow bolt (M4 hole)
- 1X M8 nut
- 1X M4 x 45mm hex head bolt
- 1X M4 nut
- 1X ¼-20 x 1.5 inch hex head bolt
- 1X ¼-20 nut
- 10X M3 brass heat-set threaded inserts
- 2X M3 x 4mm screws
- 8X M3 x 6mm screws
- 2X M3 x 16mm screws
- 2X M3 nuts
- 2X 4mm diameter, 5mm long spring ball detents with POM ball (optional)
- Thin Superglue

# Front L-Frame and Lens Frame

Steps
1. Install the M3 brass heat-set inserts into the front lens frame, ensuring that all are flush with the surface around them. Note: several holes for inserts are close to edges and you may see some deformation of the plastic when inserts are installed where the lens board and bellows are attached. If you see deformations, carefully remove them with a sharp chisel. The amount to remove is quite small, so be careful and proceed slowly to avoid slipping and damaging the front.
2. Insert the M8 hollow bolt into the rise/fall block
3. Insert the M8 plug into the remaining space in the rise/fall block and glue it, making certain that the plug is pushed in flush
4. Insert the M4 nut into the hex shaped recess on the front tilt block
5. Attach the front tilt block onto the front lens frame using two M3 screws
6. Insert the M8 nut into the rise/fall knob
7. Insert the M4 x 45mm bolt into the tilt knob
8. Insert the tilt knob cap, gluing if necessary
9. Insert the rise/fall block into the inset on the front L arm with the M8 bolt toward the outside
10. Tighten the rise/fall knob onto the protruding M8 bolt
11. Insert the tilt knob with the bolt through the center of the M8 hollow bolt and through the tilt block into the M4 nut and tighten it
12. Screw one M3 nut onto each M3 x 16mm screw, tightening it fully against the head of the screw
13. Insert each M3 x 16mm screw assembly into a thumbscrew, making certain it is in as far as possible
14. Install the thumbscrew caps onto each thumbscrew, gluing them in place
15. Install the bellows locking plate onto the bottom front of the front lens frame using M3 screws
16. Install the lens board sliding plate onto the top front of the front lens frame using the two thumbscrews
17. Insert the ¼-20 nut into the bottom of the frame QR slider
18. Install one M3 x 4mm screw into each remaining hole on the bottom of the QR slider
19. If you are using spring ball detents, insert them into the frame QR slider
20. Insert the ¼-20 bolt into the swing knob
21. Install the swing knob cap
22. Insert the swing knob and bolt through the frame QR slider and tighten

# Focusing Carriages and Racks

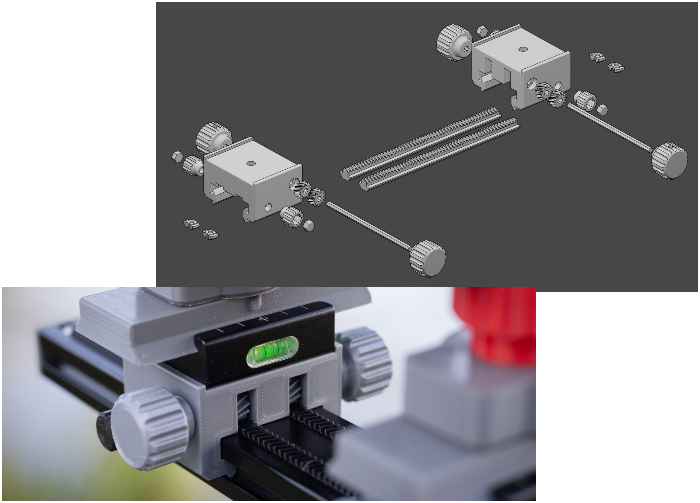
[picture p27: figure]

3D Printed Parts:

- 4X - Focus Locking Knob
- 4X - Focus Locking Knob cap
- 2X - Focusing Carriage
- 4X - Focusing Knob
- 4X - Focusing Pinion
- 4X - Focusing Rack 140mm
- 2X - Hex Focusing Axle*
- 4X - M3 T Nut

* The focusing axle can be 3D printed, but a better option is to buy long 3.5mm Allen Keys and cut them down to 88mm.
Hardware:
- 4X - 684ZZ Ball Bearings (4 x
9 x 4mm)
- 4X - M3 Nut
- 4X - M3 x 8mm screws
- 4X - M4 x 16mm hex head
screws
- 4X - M4 x 8mm set screws
- 4X - M4 heat set inserts
- 2X - Arca QR plates with mounting screws

# Focusing Carriages and Racks

Steps:

1. Insert the bearings into the focusing carriages. They are press-fit and should snap into place.
2. Install the heat set inserts into focusing carriages.
3. Insert the hex axles (or 3.5mm Allen wrenches cut to become straight 88mm lengths) into two of the focusing knobs.
4. Insert set screws into the two focusing knobs with axles. Do not overtighten - the plastic will strip.
5. Slide the axles through the carriages, slipping them through the ball bearings and pinion gears. The pinion gears will go into the two insets on the carriages so they can mate with the racks.
6. Insert the remaining focusing knobs onto the ends of the hex axles and use the remaining two set screws to hold the assemblies together.
7. The racks provided are 140mm in length. You will need four to fit into a 300mm rail. You will need to grind the mating ends of these down so that the gears match/mesh well. The fit will be very tight in the rail, and you may need to use a scraper/chisel to alter the fit. You want them snug. If you use a shorter rail, you’ll need to cut them to length.
8. Insert the M3 nuts into the 3D printed T nuts and tighten them in place at the ends of the racks. These keep the racks from slipping.
9. Insert the M4 x 16mm bolts into the focus lock knobs. Glue the focus lock knobs in place using Superglue.
10. Install the focus lock knobs into place on the carriages
11. Install the metal Arca Compatible QR plates onto the carriages. The fit will be snug and may require snapping into place
12. Install the carriages onto the rail

When printing the carriages, you should orient them with the pinion gear slots upward. No supports should be needed, but if you are worried, use Tree supports, touching the build plate only.

# Rear L-Frame and Graflok Back

3D printed parts:
- 1X Frame QR Slider
- 1X Rear L arm
- 1X Rear frame*
- 1X Repositionable back*
- 2X Graflok sliders, 1 printed as in the STL file, the other mirrored
- 4X Graflok slider spacers
- 4X Graflok slider washers
- 2X Bellows locking plates
- 1X Bubble level holder
- 1X Rear tilt block
- 1X Rise/Fall block
- 1X Rise/Fall knob
- 1X Tilt knob
- 1X Tilt knob cap
- 1X M8 plug
- 1X Swing knob
- 1X Swing knob cap

Hardware:
- 1X M8 x 20mm hollow bolt (M4 hole)
- 1X M8 nut
- 1X M4 x 45mm hex head bolt
- 1X M4 nut
- 1X ¼-20 x 1.5 inch hex head bolt
- 1X ¼-20 nut
- 11X M3 brass heat-set threaded inserts
- 8X M3 x 6mm screws
- 2X M3 x 4mm screws
- 4X M3 metal washers
- 2X 4mm diameter, 5mm long spring ball detents with POM ball (optional)
- 1X 8mm x 35m vial bubble level
- 24X 4mm x 2mm neodymium disc magnets
- Thin Superglue

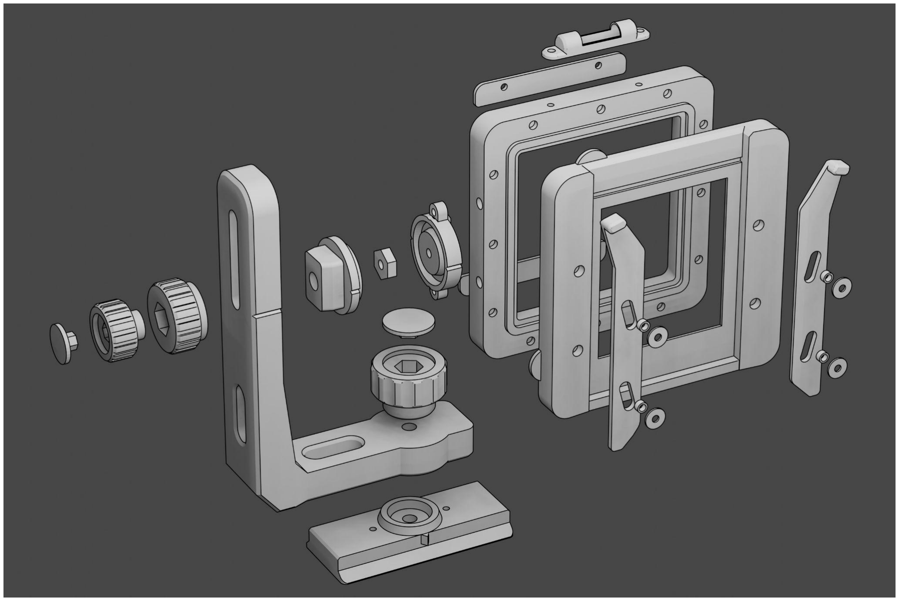
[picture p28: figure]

* If you are using 6x9 film backs, you must use the 6x9 parts instead of the standard ones.

# Rear L-Frame and Graflok Back

Steps
1. Install the M3 brass heat-set inserts into the rear frame and repositionable frame, ensuring that all are flush with the surface around them
2. Install the magnets into the rear frame. For each magnet:
a. Prior to installation put a small drop of super glue in the hole into which the magnet will be installed
b. Ensure that the magnet’s polarity is correct
c. Press the magnet fully into the hole, making certain it is flush with the surface around it
3. Install the magnets into the repositionable back. For each magnet:
a. Prior to installation put a small drop of super glue in the hole into which the magnet will be installed
b. Ensure that the magnet’s polarity is correct and that it attracts to those installed on the rear frame
c. Press the magnet fully into the hole, making certain it is flush with the surface around it
4. Insert the M8 hollow bolt into the rise/fall block
5. Insert the M8 plug into the remaining space in the rise/fall block and glue it, making certain that the plug is pushed in flush
6. Insert the M4 nut into the hex shaped recess on the rear tilt block
7. Attach the rear tilt block onto the rear frame using three M3 screws (two on the side, one on the front)
8. Insert the M8 nut into the rise/fall knob
9. Insert the M4 x 45mm bolt into the tilt knob
10. Insert the tilt knob cap, gluing if necessary
11. Insert the rise/fall block into the inset on the front L arm with the M8 bolt toward the outside
12. Tighten the rise/fall knob onto the protruding M8 bolt
13. Insert the tilt knob with the bolt through the center of the M8 hollow bolt and through the tilt block into the M4 nut and tighten it
14. Insert the ¼-20 nut into the bottom of the frame QR slider
15. Install one M3 x 4mm screw into each remaining hole on the bottom of the QR slider
16. If you are using spring ball detents, insert them into the frame QR slider
17. Insert the ¼-20 bolt into the swing knob

# Rear L-Frame and Graflok Back

18. Install the swing knob cap
19. Insert the swing knob and bolt through the frame QR slider and tighten
20. Install the 8mmx35mm vial bubble level into the bubble level holder
21. Install the bubble level holder onto the top of the rear frame with M3x6mm screws
22. Make 4 M3-6mm screws into low-profile screws. Using a drill, insert the threaded end of each M3-6mm screw into the chuck and tighten just enough to keep it in place. Run the drill and grind the head down on a piece of sandpaper until the head thickness is no more than 1.1mm. 0.9mm to 1.0mm is best.
23. Insert the Graflok spacers into each slot on the Graflok sliders, one spacer per slot
24. Install one standard metal M3 washer and then one Graflok slider washer onto each of 4 M3x6mm screws
25. Install the Graflok sliders using the M3x6mm/washers
26. Adjust the tension of the M3 screws so the sliders move sufficiently easily
27. You may need to sand down the edges that mate with your back slightly, on the edge that was in contact with your printer’s build plate. Some backs don’t seem to need this, but others do. Test-fit your back to be sure.

# Attach Tripod Mount to Rail

3D Printed Parts:
- Rail tripod mount

Hardware:
- 2X Double Tee Nuts
- 4X M5 x 10mm screws

Steps
1. Insert all 4 screws through the holes on the bottom of the rail tripod mount
2. Loosely attach the double tee nuts
3. Slide the double tee nuts into the channels on the bottom of the 20x40 aluminum extrusion
4. Tighten the M5 screws

Note: if you do not wish to use the double tee nuts, you can 3D print four (4) of the T nuts described on the focusing system and use those instead. That will be a little less convenient, but would not require you to buy double tee nuts.

# Assemble Ground Glass Holder

In addition to the option to use a bright screen instead of plain ground glass, you may choose to build a magnifying focusing hood that attaches to the ground glass holder. The idea of the magnifying focusing hood is to make it possible to use the camera without a darkcloth and focusing loupe.

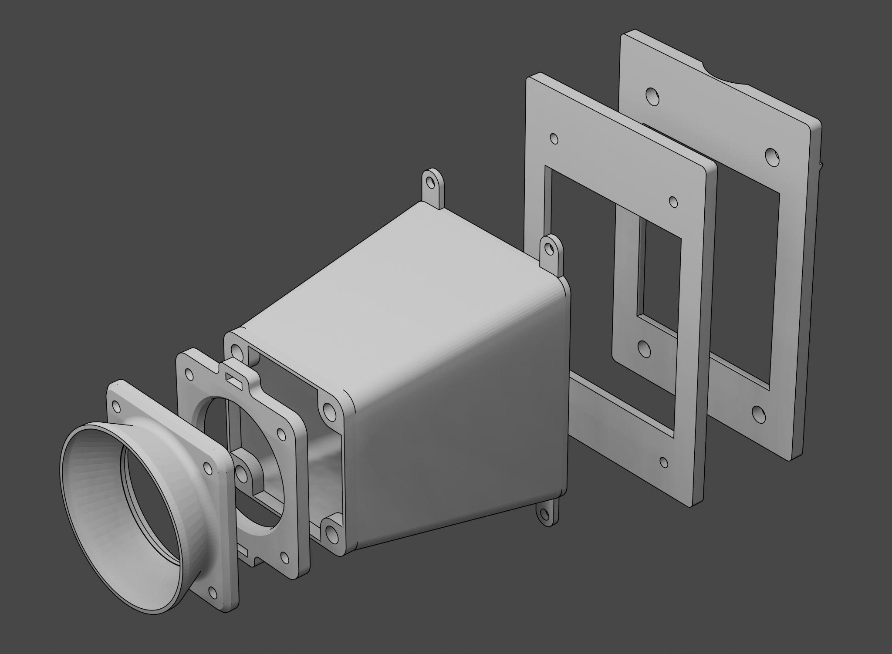
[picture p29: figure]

3D Printed Parts:
- Ground glass frame - front*
- Ground glass frame - rear*
- Magnifying hood eye cup (optional)
- Magnifying hood lower lens holder (optional)
- Magnifying hood tunnel (optional)

* if you are using a 6x9 film back, you must use the 6x9 version of these parts

Hardware:
- 4X M3 brass heat-set threaded inserts for the ground glass holder
- 4X M3 brass heat-set threaded inserts for the magnifying hood (if using the hood)
- 4X M3 x 8mm screws (if using the magnifying hood)
- 4X M3 x 6mm screws (if not using the magnifying hood)
- 4X M3 x 10mm screws (if using the magnifying hood)
- 1X plano-convex lens, 100mm focal length, 50mm diameter, Eisco brand
- 1X ground glass (either plain ground glass or Oleson bright screen

Steps:
1. Install all four M3 heat-set inserts into the front ground glass frame
2. Clean the ground glass
3. Install the glass into the rear ground glass frame, ground side facing the front ground glass frame
4. If using the magnifying hood:
a. Install the M3 heat-set inserts into the magnifying hood tunnel’s upper surface
b. Fasten the hood tunnel and the rear ground glass frame onto the front ground glass frame using the M3 x 8mm screws
c. Clean the plano-convex lens
d. Place the lens into the lower lens holder, curved side toward the ground glass
e. Fasten the eye cup and lower lens holder with lens onto the focusing hood’s outer surface using M3 x 10mm screws
5. If NOT using the magnifying hood:
a. Fasten the rear ground glass frame onto the front ground glass frame using the M3 x 6mm screws.

# Assemble Ground Glass Holder

# Mounting Bellows to the Bellows Frames

1. Trim the fabric of the bellows right up to the edge of the outermost ribs.
2. Apply contact cement to the surfaces of the bellows frames that will contact the bellows.
3. Apply contact cement to the bellows’ last ribs’ surfaces on both ends.
4. Allow the glue to dry.
5. Carefully attach the bellows to the frames and press very firmly.
6. Insert the bellows frames into their locations in the camera and secure them using bellows locking plates and M3 screws.

# Preparations to Interior Surfaces

## As a final step, you should ensure that all exposed interior surfaces of plastic are painted matte black to reduce reflections. You may also wish to paint the surfaces of your bellows frames that face towards the lens and towards the film black as

well. The interior surface of the lens board must be painted matte black.

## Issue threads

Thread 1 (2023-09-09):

Great design!

Pjeran, 2023-09-09:
Thanks for this design and putting it up for people to build.  I am hoping to make a couple of modifications to simplify the build for the materials I have on hand.  By chance would you be willing to publish STEP files to make that easier?  I am using this to teach myself FreeCAD, I imagine that you designed this in a different package.

Thanks,

Paul

MP120TC, 2023-09-09:
Paul,

I tried sending these to you but apparently the file size was too big.

https://drive.google.com/file/d/1GsuHNle3ZTGzqXknhIINtm-J-7Rqz2gy/view?usp=drive_link

When you look at these files, keep in mind that I was also in the process
of learning FreeCAD, so some things may be sub-optimal.

Also, I'm providing you these files with the same Creative Commons license
as the STL files.  Please don't distribute them to anyone else.

The geared focusing stuff is not in this ZIP file - those files are in
OnShape.  Here are the links to those parts:

https://cad.onshape.com/documents/154bf6085e68685515b69e2a/w/c17713fa6aa104f749212c94/e/2adc5de9a03f3f87c10d7f13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

https://cad.onshape.com/documents/3d9e20ffbf00a6c7043bb7ba/w/4e68b935310f1e03e893f988/e/3f4ac6acc140b1362d0a3cae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

The rack and pinion were actually from Thingiverse:
https://www.thingiverse.com/thing:2072364  I had to install OpenSCAD to
manipulate them, and it was a bit painful.

-Kent W.

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

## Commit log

2023-01-13 Add files via upload
    Initial commit
    [Bellows_Frame.stl, Bellows_Locking_Plate.stl, Bellows_Ribs_Sides_Bottom.stl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]
2023-01-13 Add files via upload
    Added image of complete camera
2023-01-13 Add files via upload
    Added 6x9 files
    [GroundGlassFrame_front_6x9.stl, GroundGlassFrame_rear_6x9.stl, Rear_Frame_6x9.stl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]
2023-08-26 Squashed commit of the following:
    commit 093aed45a7035766da10a928d675b790d781fdf1
    Author: MP120TC <122323646+MP120TC@users.noreply.github.com>
    Date: Sat Aug 26 12:44:00 2023 -0600
    Updated to geared focusing
    Updated the carriages and focusing mechanism to use 3D printed geared focusing instead of using a lead screw.
    [Bellows_Ribs_Sides_Bottom.stl, Bellows_Ribs_Tops.stl, Focus_Locking_Knob.stl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]
2023-08-26 Removed unnecessary files
    removed files no longer needed
    [Lead_Screw_Sleeve_all_plastic.stl, Lead_Screw_Sleeve_steel_tube.stl]
